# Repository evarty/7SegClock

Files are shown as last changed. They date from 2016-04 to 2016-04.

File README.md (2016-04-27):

This code is based on the AVR Atmege328p. The time is kept by a DS1307 RTC. Two button are used to set the hours and minutes. The time is displayed on 4 7-segment displays driven by 74HC595 8-bit shift registers. 
The Makefile uses avr-gcc and assumes that all needed files are present as source code in the same directory as main.c and the Makefile itself.

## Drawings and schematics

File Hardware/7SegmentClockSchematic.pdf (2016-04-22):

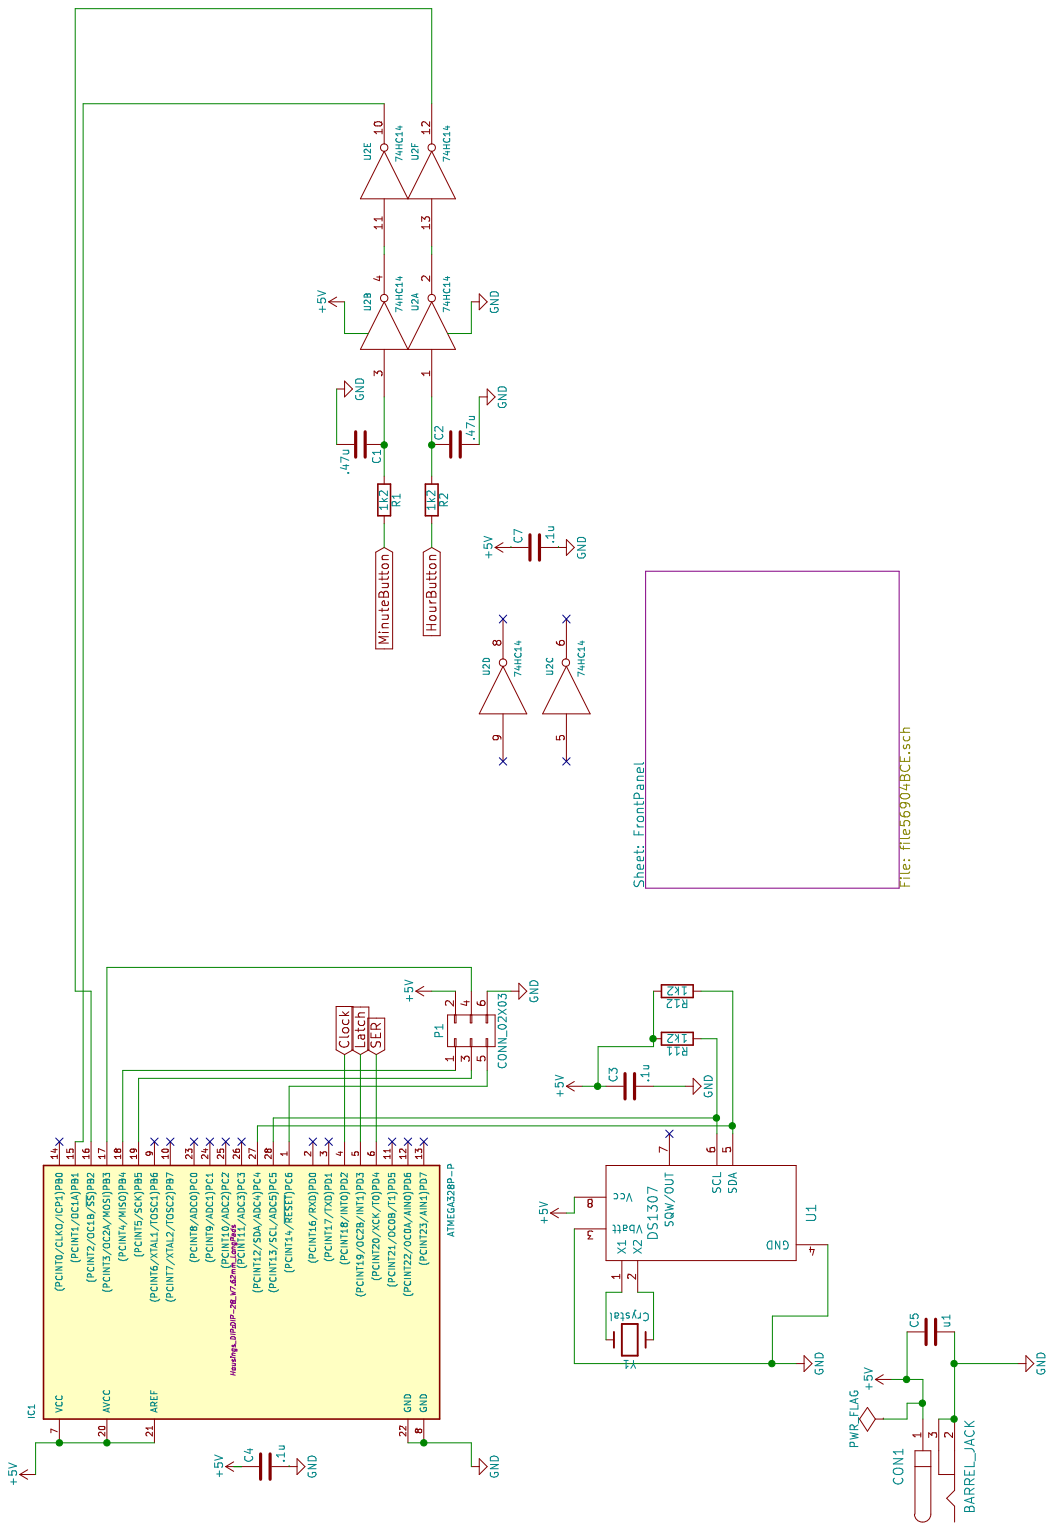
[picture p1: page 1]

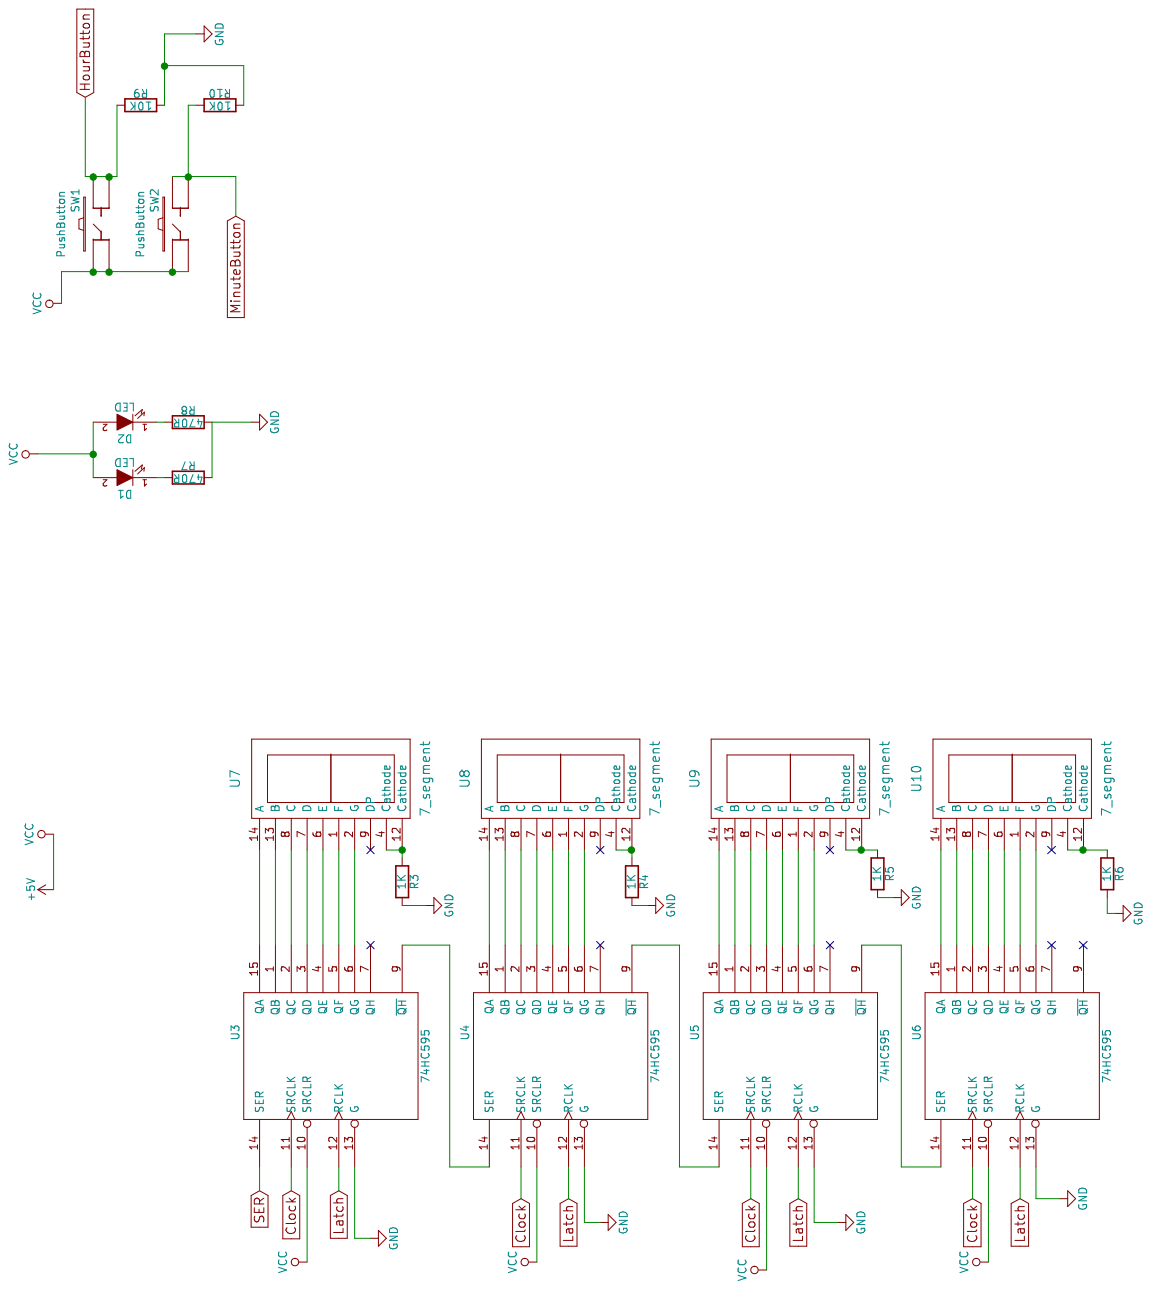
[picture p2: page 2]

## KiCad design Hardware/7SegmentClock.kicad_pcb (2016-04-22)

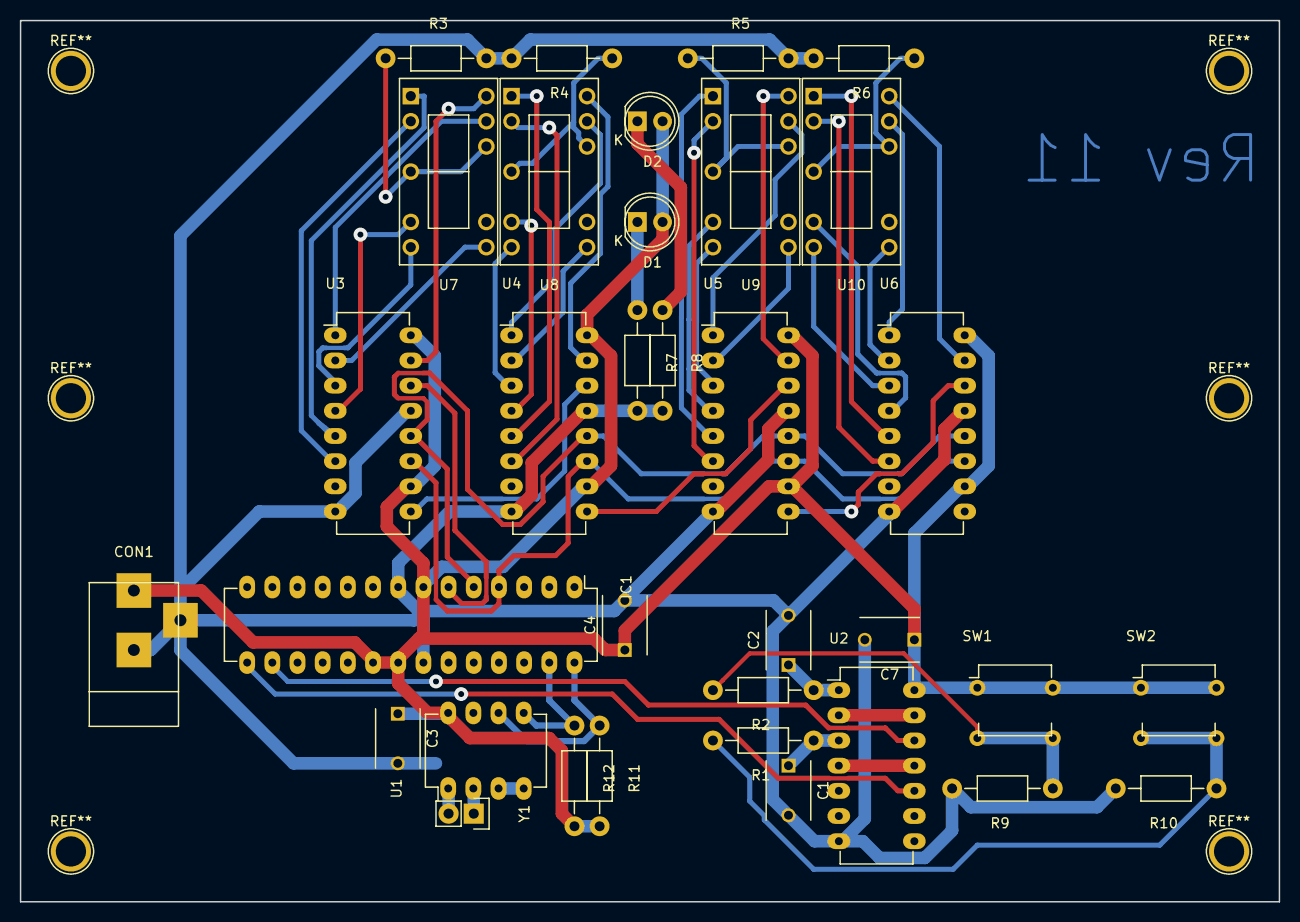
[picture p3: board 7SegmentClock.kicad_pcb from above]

Board: 2 copper layers, 127.0 x 88.9 mm, 34 parts (0 on the bottom side), 54 nets.

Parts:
C1, C2: .47u; C_Disc_D6_P5
C3, C4, C7: .1u; C_Disc_D6_P5
CON1: BARREL_JACK
D1, D2: LED; LED-5MM
IC1: ATMEGA328P-P; DIP-28_W7.62mm_LongPads
R1, R2, R11, R12: 1k2; Resistor_Horizontal_RM10mm
R3, R4, R5, R6: 1K; Resistor_Horizontal_RM10mm
R7, R8: 470R; Resistor_Horizontal_RM10mm
R9, R10: 10K; Resistor_Horizontal_RM10mm
SW1, SW2: PushButton
U1: DS1307; DIP-8_W7.62mm_LongPads
U2: 74HC14; DIP-14_W7.62mm_LongPads
U3, U4, U5, U6: 74HC595; DIP-16_W7.62mm_LongPads
U7, U8, U9, U10: 7_segment; MAN3640A
Y1: Crystal; Pin_Header_Straight_1x02

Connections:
+5V: C3.1, C4.1, C7.1, CON1.1, D1.2, D2.2, IC1.7, IC1.20, IC1.21, R11.2, R12.2, SW1.1, SW1.4, SW2.1, SW2.4, U1.8, U2.14, U3.10, U3.16, U4.10, U4.16, U5.10, U5.16, U6.10, U6.16
Clock: IC1.4, U3.11, U4.11, U5.11, U6.11
GND: C1.2, C2.2, C3.2, C4.2, C7.2, CON1.2, CON1.3, IC1.8, IC1.22, R3.2, R4.2, R5.2, R6.2, R7.2, R8.2, R9.2, R10.2, U1.3, U1.4, U2.7, U3.8, U3.13, U4.8, U4.13, U5.8, U5.13, U6.8, U6.13
HourButton: R2.2, R9.1, SW1.2, SW1.3
Latch: IC1.5, U3.12, U4.12, U5.12, U6.12
MinuteButton: R1.2, R10.1, SW2.2, SW2.3
unnamed: C1.1, R1.1, U2.3
unnamed: C2.1, R2.1, U2.1
unnamed: D1.1, R7.1
unnamed: D2.1, R8.1
unnamed: IC1.15, U2.10
unnamed: IC1.16, U2.12
unnamed: IC1.27, R12.1, U1.5
unnamed: IC1.28, R11.1, U1.6
unnamed: R3.1, U7.4, U7.12
unnamed: R4.1, U8.4, U8.12
unnamed: R5.1, U9.4, U9.12
unnamed: R6.1, U10.4, U10.12
unnamed: U1.1, Y1.2
unnamed: U1.2, Y1.1
unnamed: U2.4, U2.11
unnamed: U2.2, U2.13
unnamed: U3.1, U7.13
unnamed: U3.2, U7.8
unnamed: U3.3, U7.7
unnamed: U3.4, U7.6
unnamed: U3.5, U7.1
unnamed: U3.6, U7.2
unnamed: U3.9, U4.14
unnamed: U3.15, U7.14
unnamed: U4.1, U8.13
unnamed: U4.2, U8.8
unnamed: U4.3, U8.7
unnamed: U4.4, U8.6
unnamed: U4.5, U8.1
unnamed: U4.6, U8.2
unnamed: U4.9, U5.14
unnamed: U4.15, U8.14
unnamed: U5.1, U9.13
unnamed: U5.2, U9.8
unnamed: U5.3, U9.7
unnamed: U5.4, U9.6
unnamed: U5.5, U9.1
unnamed: U5.6, U9.2
unnamed: U5.9, U6.14
unnamed: U5.15, U9.14
unnamed: U6.5, U10.1
unnamed: U6.6, U10.2
unnamed: U6.4, U10.6
unnamed: U6.3, U10.7
unnamed: U6.2, U10.8
unnamed: U6.1, U10.13
unnamed: U6.15, U10.14
SER: IC1.6, U3.14

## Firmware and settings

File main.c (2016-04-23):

//7 segment clock based on DS1307 for timekeeping
#define F_CPU 1000000
#include <avr/io.h> //allows more human readable stuff
#include <avr/interrupt.h>  //allows interrupts 
#include <util/delay.h> //Includes delays

#include "ShiftOut.h"//outputs to shfit registers, in particular 74HC595
#include "IIC.h"//IIC library
#include "DS1307.h"//functions to interact with DS1307


//define pins for 7 seg output 
#define LatchPin 3
#define DataPin 4
#define ClockPin 2


//define button pins
#define HourPort PINB
#define HourMask 0x02 //B1
#define MinutePort PINB
#define MinuteMask 0x04 //B2


//define variables that will be affected by ISR
volatile uint8_t HourButton = 0;
volatile uint8_t MinuteButton = 0;


int main(void){
  _delay_ms(50);//brief delay to allow DS1307 to init
  //set up output pins
  DDRD = 0xFF;//set all Port D pins to be outputs
  //define 7 seg output values
  uint8_t numbers[] = {252,96,218,242,102,182,62,224,254,230};//numbers[i] outputted will show up as digit "i"


  //init clock chip (ds1307)
  TWIInit();
  DS1307Init();

  //set up timer0
  TCCR0A |= (0 << CS02);
  TCCR0B |= (1 << CS01) | (1 << CS00);
  TIMSK0 |= (1 << TOIE0);
  sei(); 

  while(1){  

    //define variables to hold current hours and minutes
    static uint8_t Minutes = 0, Hours = 0;
    //read current time from clock
    cli();
    Minutes = DS1307RegisterR(0x01);
    Hours = DS1307RegisterR(0x02);
    sei();

    //define state variables
    static uint8_t HourAdd = 0, MinuteAdd = 0, HourState = 0, MinuteState = 0;
    //define working variables
    static uint8_t MinutesOnes = 0, MinutesTens = 0, HoursOnes = 0, HoursTens = 0;

    //separate digits from read values
    MinutesOnes = Minutes & 0x0F;//the ones value is the lower nibble
    MinutesTens = (Minutes & 0x70) >> 4;//the tens value is the lower 3 bits in the upper nibble
    HoursOnes = Hours & 0x0F;//the ones value is the lower nibble
    HoursTens = (Hours & 0x30) >> 4;//The tens values is the lower 2 bits in the upper nibble

    //output to 7 segment displays
    ShiftOutByte(ClockPin, &PORTD, DataPin, &PORTD, LatchPin, &PORTD, numbers[MinutesOnes]);
    ShiftOutByte(ClockPin, &PORTD, DataPin, &PORTD, LatchPin, &PORTD, numbers[MinutesTens]);
    ShiftOutByte(ClockPin, &PORTD, DataPin, &PORTD, LatchPin, &PORTD, numbers[HoursOnes]);
    ShiftOutByte(ClockPin, &PORTD, DataPin, &PORTD, LatchPin, &PORTD, numbers[HoursTens]);


    //signal if adding an hour, deal with hour state
    if(HourButton && !HourState){//if the hour button has been pressed and the hour has not been dealt with yet, enter the conditional
      HourAdd = 1;//signal that the hour variable needs to be incremented
      HourState = 1;//set state variable
    }else if(!HourButton && HourState){//if the hour button has not been pressed and the state variable is still set, clear state bit.
      HourState = 0;
    }else {;}

    //signal if adding a minute, deal with minute state
    //same logic as the hours
    if(MinuteButton && !MinuteState){
      MinuteAdd = 1;
      MinuteState = 1;
    }else if(!MinuteButton && MinuteState){
      MinuteState = 0;
    }else {;}


    //add an hour, account for base 10 stuff
    if(HourAdd){
      HoursOnes += 1;
      if((HoursOnes == 4) && (HoursTens == 2)){
        HoursTens = 0;
        HoursOnes = 0;
      }else if((HoursOnes == 10) && (HoursTens < 2)){
        HoursTens += 1;
        HoursOnes = 0;
      }

      cli();
      DS1307RegisterW(0x02, 0x00 | (HoursTens << 4) | (HoursOnes << 0));//write the new hours back to the DS1307
      sei();
      HourAdd = 0;
    }

    //add a minute, account for base 10 stuff
    if(MinuteAdd){
      MinutesOnes += 1;
      if((MinutesOnes == 10) && (MinutesTens == 5)){
        MinutesTens = 0;
        MinutesOnes = 0;
      }else if((MinutesOnes == 10) && (MinutesTens < 6)){
        MinutesTens += 1;
        MinutesOnes = 0;
      }

      cli();
      DS1307RegisterW(0x01, 0x00 | (MinutesTens << 4) | (MinutesOnes << 0));//write the new minutes back to the DS1307
      sei();

      MinuteAdd = 0;
    }


  }
}


ISR(TIMER0_OVF_vect){//ISR takes ~14 us, occurs every ~15ms

  //check if button pressed and indicate either way
  if(HourPort & HourMask){
    HourButton = 1;
  }else{
    HourButton = 0;
  }

  if(MinutePort & MinuteMask){
    MinuteButton = 1;
  }else{
    MinuteButton = 0;
  } 

}

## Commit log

2016-04-20 Adding PCB
    [ClockMerge.kicad_pcb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]
2016-04-22 added KiCadFiles
    [7SegmetClock.kicad_pcb, 7SegmetClock.sch, file56904BCE.sch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]
2016-04-22 added gerbers
    [7SegmetClock-B.Cu.gbr, 7SegmetClock-B.Mask.gbr, 7SegmetClock-B.SilkS.gbr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]
2016-04-22 moved the board files to a new directory
    [7SegmentClock-B.Mask.gbr, 7SegmentClock-B.SilkS.gbr, 7SegmentClock-Edge.Cuts.gbr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]
2016-04-22 moved filename
    [7SegmentClock-B.Mask.gbr, 7SegmentClock-B.SilkS.gbr, 7SegmentClock-Edge.Cuts.gbr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]
2016-04-22 added pdf schematic
